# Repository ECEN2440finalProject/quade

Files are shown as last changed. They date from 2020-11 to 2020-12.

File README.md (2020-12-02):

# quade
ECEN 2440 quade code

Repository for RC Quade (Quadruped robot with MSP432 as its base, controlled wirelessly by a remote control with joystick).

ECEN 2440 Final Project Team 11 - Michael L, Terry V, Wyatt S, Ethan C

Fall, 2020

All code files (original and leveraged) can be found here, along with:
  - Texas Instruments MSP432P401R LaunchPad datasheet, header file, and Technical Reference Manual (quade/Datasheet_TechRefMan/)
  - EAGLE PCB schematic and board design files for Arduino Uno shield, for remote control (quade/Arduino_Uno_Shield/)

Works Cited/Leveraged Code:
  - Tyler Davidson: IMU_TestBench code (stIMU.c/.h, pca9685.c/.h, i2c.c/.h, parts of main.c); FirstSteps code (servo.c/.h, parts of gait.c/.h)
  - Paul Stoffregen: RadioHead library (basis of our custom Arduino sketch for RF Link Transmitter)
    - https://github.com/PaulStoffregen/RadioHead
  - Texas Instruments, Inc: MSP432 Driver Library (used for ADC code)
    - adc14.c/.h, cpu.c/.h, debug.h, gpio.c/.h, interrupt.c/.h, sysctl.c/.h, sysctl_a.c/.h
    - https://software-dl.ti.com/msp430/msp430_public_sw/mcu/msp430/MSP432_Driver_Library/latest/index_FDS.html

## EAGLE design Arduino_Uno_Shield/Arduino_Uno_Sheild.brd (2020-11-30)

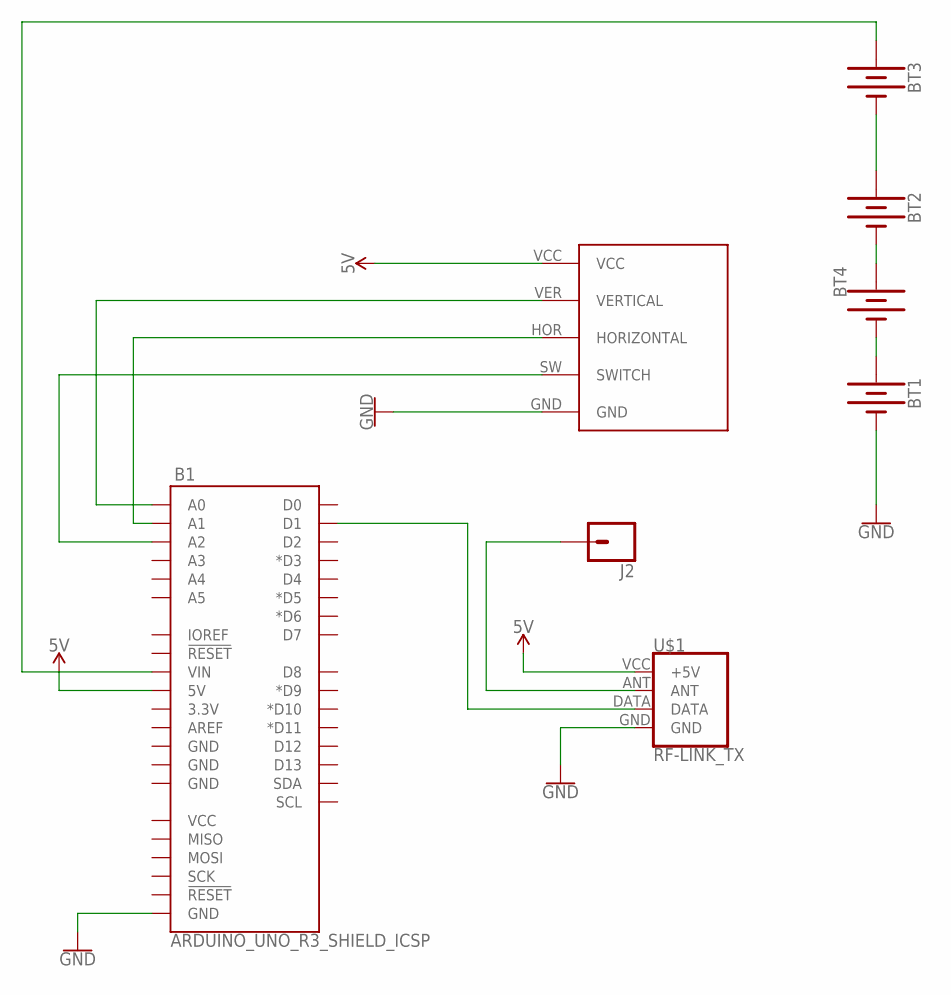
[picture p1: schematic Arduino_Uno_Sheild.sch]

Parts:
B1: ARDUINO_UNO_R3_SHIELD_ICSP; UNO_R3_SHIELD_ICSP
BT1, BT2, BT3, BT4: BATTERY-AAA
J2: CONN_01POGOPIN_HOLE_0.58; 1X01_POGOPIN_HOLE_0.58_DIA
JOYSTICK1: JOYSTICK
U$1: RF-LINK_TX

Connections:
5V: B1.5V, JOYSTICK1.VCC, U$1.VCC (+5V)
GND: B1.GND_ICSP (GND), BT1.GND@1 (-), JOYSTICK1.GND, U$1.GND
unnamed: B1.TX (D1), U$1.DATA
unnamed: J2.1, U$1.ANT
unnamed: B1.A0, JOYSTICK1.VER (VERTICAL)
unnamed: B1.A1, JOYSTICK1.HOR (HORIZONTAL)
unnamed: B1.A2, JOYSTICK1.SW (SWITCH)
unnamed: B1.VIN, BT3.PWR@1 (+)
unnamed: BT2.PWR@1 (+), BT3.GND@1 (-)
unnamed: BT2.GND@1 (-), BT4.PWR@1 (+)
unnamed: BT1.PWR@1 (+), BT4.GND@1 (-)

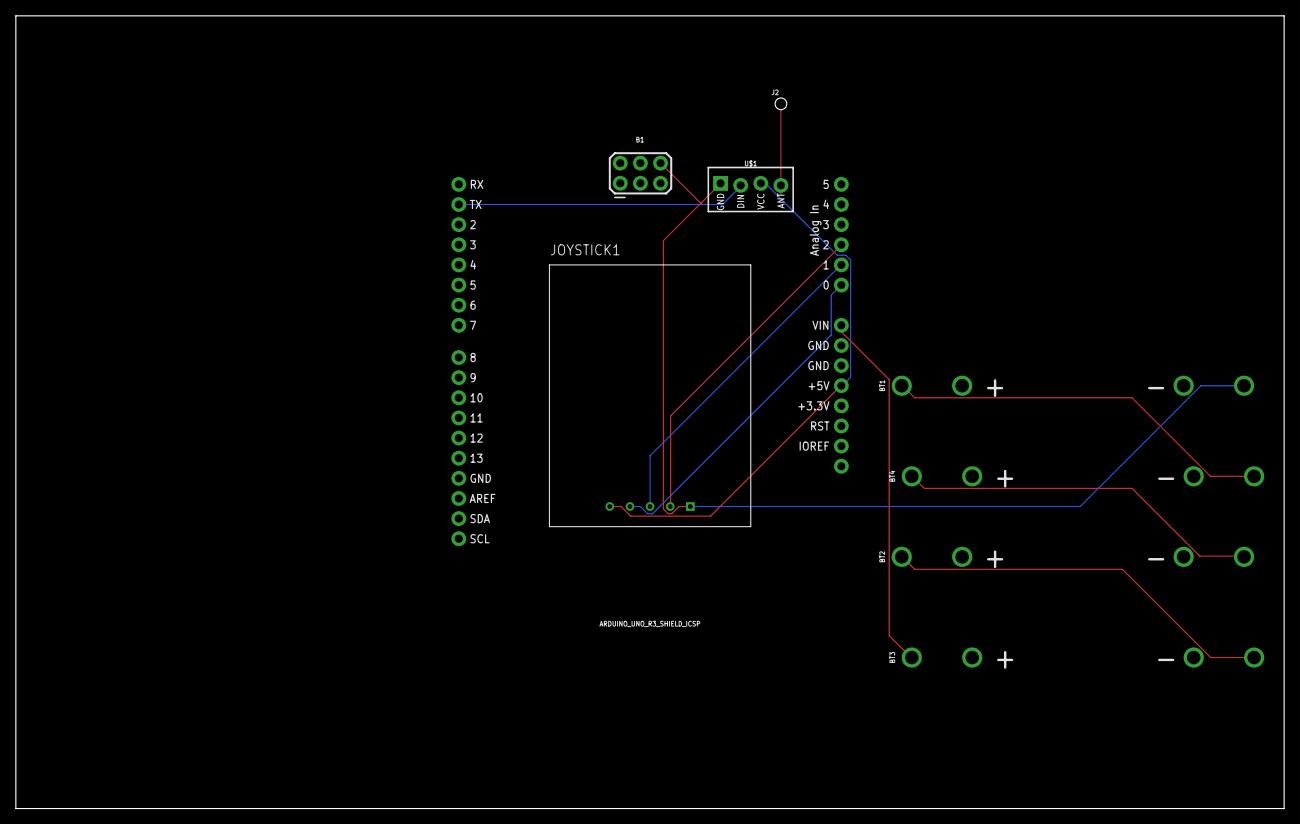
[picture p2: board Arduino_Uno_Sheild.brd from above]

Board: 2 copper layers, 160.0 x 100.0 mm, 8 parts (0 on the bottom side), 11 nets.

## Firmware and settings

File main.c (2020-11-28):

//ATTENTION!!!!
//PLEASE IGNORE BELOW DIAGRAM!!!
//THis diagram was back when I was using my own Naming Convention
//Check servo.h for servo channels



/*This Program is designed to allow all the servos to be attached
 * to the skeleton in a predictable way.
 *
 * In order to have proper orientation and operation of the robot,
 * a consistent convention must be established. Below is a top-down
 * view of the robot. The boxes represent each servo and the name
 * assigned to it. Each Group (A-D) represents a limb, while each
 * number represents a joint (1 is shoulder, 2 is knee)
 *
 *    ____                         ____
 *   /    \                       /    \
 *  /  A2  \      TOP-DOWN       /  B2  \
 *  \______/                     \______/
 *         \ ______       ______ /
 *          |      |     |      |
 *          |  A1  |     |  B1  |
 *          |______|     |______|
 *              |           |
 *  FRONT ------------------------- BACK
 *           ___|__       __|___
 *          |      |     |      |
 *          |  D1  |     |  C1  |
 *          |______|     |______|
 *     ____/                     \____
 *    /    \                     /    \
 *   /  D2  \                   /  C2  \
 *   \______/                   \______/
 *
 * It is very important that all the Shoulder-Knee joints get assembled
 * EXACTLY the same. This will guarantee that all the Knee servos behave
 * the same.
 *
 * When the program is initially started, the servos will move to their
 * center postiton (90 degrees).
 *
 * For the first time using this program
 * MAKE SURE THAT NO SERVOS ARE SECURED TO THE SKELETON!! There is a
 * serious risk that the servos will collide with each other if they
 * aren't secured in the correct position.
 *
 * Once all the servos are centered, it is time to attach the servos
 * the skeleton in what is called the Neutral Position. In the Neutral
 * Position, the horn of the servo should be be in-line or parallel to
 * the body of the servo (or as close as possible). The Horn of the
 * servo is used to secure the servo in the correct position
 *
 * Below is the pinning information to connect servos to PCA9685 board
 *
 *   A1-->Group A, servo 1 to servo pin 0 (of PCA9685)
 *   A2-->Group A, servo 2 to servo pin 1 (of PCA9685)
 *   B1-->Group B, servo 1 to servo pin 2 (of PCA9685)
 *   B2-->Group B, servo 2 to servo pin 3 (of PCA9685)
 *   C1-->Group C, servo 1 to servo pin 4 (of PCA9685)
 *   C2-->Group C, servo 2 to servo pin 5 (of PCA9685)
 *   D1-->Group D, servo 1 to servo pin 6 (of PCA9685)
 *   D2-->Group D, servo 2 to servo pin 7 (of PCA9685)
 *
 * Once all the servos are secured in the Neutral Position,
 * pressing the button (S1) on the MSP432 will cause the robot to stand
 * up.
 *
 * IF THE ROBOT DOES NOT STAND UP CORRECTLY, SOMETHING ELSE IS WRONG!
 * Check:
 *       -Servo Orientation at the knee joints
 *       -Wiring to PCA
 *       -Servo Neutral Position
 *
 * MSP Wiring:
 *
 *         msp432p401r
 *      -----------------
 *     |                 |
 *     |                 |
 *     |             P1.7|-->SCL (PCA9685)
 *     |             P1.6|-->SDA (PCA9685)
 *     |                 |
 *     |                 |
 *     |              3V3|-->VCC (PCA9685)
 *     |              GND|-->GND (PCA9685)
 *     |                 |
 *     |_________________|
 *
 *
 *
 *  By: Tyler Davidson
 *  Date: July 17th, 2020
 *
 *  Modified by: Terry Vis
 *  Date: Nov 9, 2020
 *
 */

#include "msp.h"
#include "i2c.h"
#include "pca9685.h"
#include "servo.h"
#include "stIMU.h"
#include "stdio.h"
#include "assert.h"

#include "uart.h"
#include "RFlink.h"
#include "parse_joystick.h"
#include "gait.h"
#include "thermistor.h"


volatile int state = 0;
/*
 * States:
 * 0 - Quade neutral (don't write data to servos)
 * 1 - Read data from Rx UART buffer, make calculations
 * 2 - Write data to servos
 */

// For joystick:
// Up/left is positive direction
// (outputs high for these directions, low for down/right, 1/2 for neutral)

static RX_UART_BUF_TypeDef rx_uart_buf;
static UART_PAYLOAD_TypeDef uart_payload_struct;
static RX_UART_TypeDef rx_uart_struct, *rx_read_struct;

void main(void)
 {
	WDT_A->CTL = WDT_A_CTL_PW | WDT_A_CTL_HOLD;		// stop watchdog timer
	config_uart();
	config_uart_interrupt();
	config_rx_gpio();
	start_uart();

	// Configure and start ADC
	adc_config();
	adc_pin_config();
	adc_enable_interrupt();
	start_adc();

	// set up Button Interrupt
    P1->DIR &= ~BIT1;
    P1->OUT |= BIT1;
    P1->REN |= BIT1;
    P1->IES |= BIT1;
    P1->IFG = 0;
    P1->IE  |= BIT1;

    // Configure data for Rx buffer
    rx_uart_buf.size = 8;
    rx_uart_buf.read = 0;
    rx_uart_buf.write = 0;

    //enable interrupts
    NVIC_EnableIRQ(PORT1_IRQn);
	__enable_irq();

    I2C_OPEN_STRUCT_TypeDef i2c_open_struct;

    i2c_open_struct.uca10 = 0;                              //no self 10-bit Address
    i2c_open_struct.ucsla10 = 0;                            //no 10-bit Addressing
    i2c_open_struct.ucmm = 0;                               //No Multi-Master
    i2c_open_struct.ucmst = EUSCI_B_CTLW0_MST;              //Master Mode
    i2c_open_struct.ucsselx = EUSCI_B_CTLW0_SSEL__SMCLK;    //SMCLK to be selected (3MHz)
    i2c_open_struct.ucbrx = 30;                             //Prescaler for Selected Clock.
                                                            //(100kHz)

    //This sets up the I2C driver to operate with the
    //correct settings.
    //EUSCI_B0 uses P1.7 as SCL and P1.6 as SDA
    i2c_open(EUSCI_B0, &i2c_open_struct);

    pca9685_init(); //sets up PCA to output at the correct frequency
    config_LIS3MDL();

    int16_t mx, my, mz;
    uint8_t data;
    int i;


    //Neutral Position
    while(state == 0){
        for(i=0; i<200000; i++);
        i2c_start(EUSCI_B0, LIS3MDL_MAG_I2C_ADDRESS, READ, &data, 1, LIS3MDL_MAG_STATUS_REG);
        i2c_start(EUSCI_B0, LIS3MDL_MAG_I2C_ADDRESS, READ, &data, 1, LIS3MDL_MAG_STATUS_REG);
        printf("status 1: %d\n",data);
        for(i=0; i<1000; i++);
        mx = read_magnetometer_x();
        my = read_magnetometer_y();
        mz = read_magnetometer_z();
        printf("x: %d\n", mx);
        printf("y: %d\n", my);
        printf("z: %d\n", mz);
        printf("status: %d\n", data);
        printf("\n");
        printf("\n");
        printf("\n");
        printf("\n");
    }

    int8_t * pos; // pointer to array for position of joystick
    uint8_t err;

    // Infinite loop for Quade motion -- interrupt for other functions
    while (state) {
        if (state==1) {
            err = rx_buf_read(&rx_uart_buf, rx_read_struct);
            joystick_pos(rx_read_struct, pos);
            // check for successful read (make sure buffer is not empty for this cycle)
            // if successful, break out of loop, write to servos next
            state = err ? 1 : 2;
        }

        else if (state==2) {
            // write to servos
            servo_gait(pos);
            state = 1;
        }

        else state = 1; // if state does not equal 1 or 2, set to 1 (read state)
    }

}

// putting this here for ease of struct/buffer handling
void EUSCIA2_IRQHandler(void) {
    // check each flag, then perform necessary function
    if (UART_P->IFG & EUSCI_A_IFG_RXIFG) {
        UART_P->IFG &= ~EUSCI_A_IFG_RXIFG; // clear flag

        // store RXBUF bits, will empty buffer
        uint8_t rx = UART_P->RXBUF & EUSCI_A_RXBUF_RXBUF_MASK;
        *uart_payload_struct.data = rx;

        if (rx_uart_struct.i == rx_uart_struct.length) {
            rx_buf_write(&rx_uart_buf, rx_uart_struct);
            rx_uart_struct.i = 0; // reset iteration variable
        }

        rx_state(rx, &rx_uart_struct);



    }
}

/* Port1 ISR */
void PORT1_IRQHandler(void){
    volatile uint32_t j;

    //Change State to Standing Position
    if(P1->IFG & BIT1)
        state = 1;

    // Delay for switch debounce
    for(j = 0; j < 100000; j++);

    // Initialize standing position
    servo_write(URL,90-45); //Because the Orientations are opposite of the other servos,
    servo_write(LRL,90-45); //the direction the servo must move to stand up is also opposote
    servo_write(URA,90+45);
    servo_write(LRA,90+45);
    servo_write(ULL,90+45);
    servo_write(LLL,90+45);
    servo_write(ULA,90-45); //See Above Comment
    servo_write(LLA,90-45);
    wait_all_reach();

    P1->IFG &= ~BIT1;
}

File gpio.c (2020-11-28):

/* --COPYRIGHT--,BSD
 * Copyright (c) 2017, Texas Instruments Incorporated
 * All rights reserved.
 *
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
 * *  Redistributions of source code must retain the above copyright
 *    notice, this list of conditions and the following disclaimer.
 *
 * *  Redistributions in binary form must reproduce the above copyright
 *    notice, this list of conditions and the following disclaimer in the
 *    documentation and/or other materials provided with the distribution.
 *
 * *  Neither the name of Texas Instruments Incorporated nor the names of
 *    its contributors may be used to endorse or promote products derived
 *    from this software without specific prior written permission.
 *
 * THIS SOFTWARE IS PROVIDED BY THE COPYRIGHT HOLDERS AND CONTRIBUTORS "AS IS"
 * AND ANY EXPRESS OR IMPLIED WARRANTIES, INCLUDING, BUT NOT LIMITED TO,
 * THE IMPLIED WARRANTIES OF MERCHANTABILITY AND FITNESS FOR A PARTICULAR
 * PURPOSE ARE DISCLAIMED. IN NO EVENT SHALL THE COPYRIGHT OWNER OR
 * CONTRIBUTORS BE LIABLE FOR ANY DIRECT, INDIRECT, INCIDENTAL, SPECIAL,
 * EXEMPLARY, OR CONSEQUENTIAL DAMAGES (INCLUDING, BUT NOT LIMITED TO,
 * PROCUREMENT OF SUBSTITUTE GOODS OR SERVICES; LOSS OF USE, DATA, OR PROFITS;
 * OR BUSINESS INTERRUPTION) HOWEVER CAUSED AND ON ANY THEORY OF LIABILITY,
 * WHETHER IN CONTRACT, STRICT LIABILITY, OR TORT (INCLUDING NEGLIGENCE OR
 * OTHERWISE) ARISING IN ANY WAY OUT OF THE USE OF THIS SOFTWARE,
 * EVEN IF ADVISED OF THE POSSIBILITY OF SUCH DAMAGE.
 * --/COPYRIGHT--*/
/* Standard Includes */
#include <stdint.h>

/* DriverLib Includes */
#include <gpio.h>
#include <debug.h>
#include <interrupt.h>


static const uint32_t GPIO_PORT_TO_INT[] =
{ 0x00,
INT_PORT1,
INT_PORT2,
INT_PORT3,
INT_PORT4,
INT_PORT5,
INT_PORT6 };

static const uint32_t GPIO_PORT_TO_BASE[] =
{   0x00,
    (uint32_t)P1,
    (uint32_t)P1+1,
    (uint32_t)P3,
    (uint32_t)P3+1,
    (uint32_t)P5,
    (uint32_t)P5+1,
    (uint32_t)P7,
    (uint32_t)P7+1,
    (uint32_t)P9,
    (uint32_t)P9+1,
    (uint32_t)PJ
};

void GPIO_setAsOutputPin(uint_fast8_t selectedPort, uint_fast16_t selectedPins)
{
    uint32_t baseAddress = GPIO_PORT_TO_BASE[selectedPort];

    HWREG16(baseAddress + OFS_LIB_PASEL0) &= ~selectedPins;
    HWREG16(baseAddress + OFS_LIB_PASEL1) &= ~selectedPins;
    HWREG16(baseAddress + OFS_LIB_PADIR) |= selectedPins;
}


void GPIO_setAsInputPin(uint_fast8_t selectedPort, uint_fast16_t selectedPins)
{
    uint32_t baseAddress = GPIO_PORT_TO_BASE[selectedPort];

    HWREG16(baseAddress + OFS_LIB_PASEL0) &= ~selectedPins;
    HWREG16(baseAddress + OFS_LIB_PASEL1) &= ~selectedPins;
    HWREG16(baseAddress + OFS_LIB_PADIR) &= ~selectedPins;
    HWREG16(baseAddress + OFS_LIB_PAREN) &= ~selectedPins;
}


void GPIO_setAsPeripheralModuleFunctionOutputPin(uint_fast8_t selectedPort,
        uint_fast16_t selectedPins, uint_fast8_t mode)
{

    uint32_t baseAddress = GPIO_PORT_TO_BASE[selectedPort];

    HWREG16(baseAddress + OFS_LIB_PADIR) |= selectedPins;
    switch (mode)
    {
    case GPIO_PRIMARY_MODULE_FUNCTION:
        HWREG16(baseAddress + OFS_LIB_PASEL0) |= selectedPins;
        HWREG16(baseAddress + OFS_LIB_PASEL1) &= ~selectedPins;
        break;
    case GPIO_SECONDARY_MODULE_FUNCTION:
        HWREG16(baseAddress + OFS_LIB_PASEL0) &= ~selectedPins;
        HWREG16(baseAddress + OFS_LIB_PASEL1) |= selectedPins;
        break;
    case GPIO_TERTIARY_MODULE_FUNCTION:
        HWREG16(baseAddress + OFS_LIB_PASEL0) |= selectedPins;
        HWREG16(baseAddress + OFS_LIB_PASEL1) |= selectedPins;
        break;
    }
}


void GPIO_setAsPeripheralModuleFunctionInputPin(uint_fast8_t selectedPort,
        uint_fast16_t selectedPins, uint_fast8_t mode)
{
    uint32_t baseAddress = GPIO_PORT_TO_BASE[selectedPort];

    HWREG16(baseAddress + OFS_LIB_PADIR) &= ~selectedPins;
    switch (mode)
    {
    case GPIO_PRIMARY_MODULE_FUNCTION:
        HWREG16(baseAddress + OFS_LIB_PASEL0) |= selectedPins;
        HWREG16(baseAddress + OFS_LIB_PASEL1) &= ~selectedPins;
        break;
    case GPIO_SECONDARY_MODULE_FUNCTION:
        HWREG16(baseAddress + OFS_LIB_PASEL0) &= ~selectedPins;
        HWREG16(baseAddress + OFS_LIB_PASEL1) |= selectedPins;
        break;
    case GPIO_TERTIARY_MODULE_FUNCTION:
        HWREG16(baseAddress + OFS_LIB_PASEL0) |= selectedPins;
        HWREG16(baseAddress + OFS_LIB_PASEL1) |= selectedPins;
        break;
    }
}


void GPIO_setOutputHighOnPin(uint_fast8_t selectedPort,
        uint_fast16_t selectedPins)
{

    uint32_t baseAddress = GPIO_PORT_TO_BASE[selectedPort];

    HWREG16(baseAddress + OFS_LIB_PAOUT) |= selectedPins;
}


void GPIO_setOutputLowOnPin(uint_fast8_t selectedPort,
        uint_fast16_t selectedPins)
{

    uint32_t baseAddress = GPIO_PORT_TO_BASE[selectedPort];

    HWREG16(baseAddress + OFS_LIB_PAOUT) &= ~selectedPins;
}
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

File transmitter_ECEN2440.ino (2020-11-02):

/*
 * --------------------Constants----------------------
 */

// baud rate
const long baud = 50;

// message length
const uint8_t msgLength = 3;

// start/ stop characters 
const uint16_t Start = 0xF000; //1111_0000_0000_0000
const uint16_t Stop = 0xFF00;  //1111_1111_0000_0000

// post message delay
const long postDelay = 1000;

// analog pins for reading joystick voltage
const int ver = A0;
const int hor = A1;
const int sw = A2;

/*
 * -------------------Structures--------------------
 */

//struct to hold data
struct data{
  uint16_t ver;
  uint16_t hor;
  uint16_t sw;
};

/*
 * -------------------Functions--------------------
 */

//takes in a data struct and fills the struct from the analog sources
//returns nothing
void readPins(data * D){
  D->ver = analogRead(ver);
  D->hor = analogRead(hor);
  D->sw = analogRead(sw);
}

//takes in a two byte variable
//returns void, updates array LSByte first
void parseData(uint16_t twoBytes, uint8_t * arr){
  //parse the 16 bit value into two 8 bit values LSB first
  arr[1] = static_cast<uint8_t>((twoBytes & 0xFF00) >> 8);
  arr[0] = static_cast<uint8_t>(twoBytes & 0x00FF);
}

/*
 * Least Significant Byte first, Least Significant Bit first
 * start   len msg1    msg2    msg3    stop
 * 00__0F__30__LS__MS__LS__MS__LS__MS__00__FF
 */
void sendData(data * D){
  //two byte arrays to send
  uint8_t st[2] = {0,0};
  uint8_t sp[2] = {0,0};
  uint8_t ver[2] = {0,0};
  uint8_t hor[2] = {0,0};
  uint8_t sw[2] = {0,0};

  //two byte ints parsed into bytes and placed in two byte arrays
  parseData(Start, st);
  parseData(Stop, sp);
  parseData(D->ver, ver);
  parseData(D->hor, hor);
  parseData(D->sw, sw);
  
  //send the start 
  Serial.write(st, sizeof(st));
  
  //send the length of the message
  Serial.write(msgLength);
  
  //send the message
  Serial.write(ver, sizeof(ver));
  Serial.write(hor, sizeof(hor));
  Serial.write(sw, sizeof(sw));

  //send the stop
  Serial.write(sp, sizeof(sp));
  
  delay(postDelay);
}
/*
 *--------------------Setup-------------------------
 */
void setup() {
  // open serial port for transmit, uses baud rate from above
  // 8 bit word length, no parity, one stop bit
  Serial.begin(baud, SERIAL_8N1);
}

/*
 *-------------------- Main-------------------------
 */

void loop() {
  // instantiate data struct
  data D = {0,0,0};
  
  //read analog pins
  readPins(&D);
  
  //send the data
  sendData(&D);
}

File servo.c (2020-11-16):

/*
 * servo.c
 *
 * This driver is designed to give xyz control over all the limbs.
 * This will make it much easier to program movement for any kind of gait
 * because the angles can be disregarded. Additional functionality include
 * speed control of the limbs as well as moving several limbs simultaneously
 * thanks to a TimerA interrupt-driven scheduler.
 *
 * Much of this code is inspired by other work.
 * Many of the main functions are built from the work of
 * Belkhir Mohamed. Below is the information that he has requested we provide.
 *
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
 *
 *
 *
 *
 *  Created on: Jul 14, 2020
 *      Author: Tyler Davidson
 *     Updated: Aug 13, 2020
 */
#include "servo.h"
#include "math.h"

void xyz_to_angle(int limb, volatile float *t1, volatile float *t2, volatile float x, volatile float y, volatile float z);
void servo_service(void);
void angle_to_servo(int limb, float t1, float t2);

//flag to indicate the need to service the servos
volatile bool timer_flag = false;

//matrix to organize all servos in the system
const int Servo[4][2] = { {URA,LRA} , {ULA,LLA} , {ULL,LLL} , {URL,LRL} };
//    Servo Matrix
//  __|_0_|_1_|_2_|_3_
//  0_|URA|ULA|URL|ULL
//  1_|LRA|LLA|LRL|LLL


volatile float  pos_now[4][3];         //current coords of each foot (xyz)
volatile float  pos_expected[4][3];    //expected coords of each foot
float           temp_speed[4][3];      //Incremental value to control speed of movement

/*
 * This function is designed to set the starting position for all
 * the limbs and update the arrays for first time use
 */
void servo_startup(){

    int i;
    int j;

    for(i=0; i<4; i++){
        for(j=0; j<2; j++){
            servo_write(Servo[i][j], 90);
        }
    }


    //updates array to represent the correct location
    for(i=0; i<4; i++){
        for(j=0; j<3; j++){
            pos_now[i][j] = 0;
        }
    }


    pos_now[0][0] = A1+A2;
    pos_now[1][0] = -(A1+A2);
    pos_now[2][0] = -(A1+A2);
    pos_now[3][0] = A1+A2;



}


/*
 * Sets up TimerA0 to request servicing of the servos every 20ms.
 * Uses SMCLK @ 3MHz
 */
void servo_timer_init(void){
    TIMER_A0->CCTL[0] &= ~TIMER_A_CCTLN_CCIFG;
    TIMER_A0->CCTL[0] = TIMER_A_CCTLN_CCIE; // TACCR0 interrupt enabled
    TIMER_A0->CCR[0] = 60000;               //count to 60,000 at 3MHz (T = 20ms)
    TIMER_A0->CTL = TIMER_A_CTL_SSEL__SMCLK | // SMCLK , UP mode
            TIMER_A_CTL_MC__UP;
    NVIC_EnableIRQ(TA0_0_IRQn);


}


/*
 * This function checks each limb and moves them by an incrimental amount
 * based on the speed established inside the set_pos function. This function calls two very
 * large functions and requires a lot of time to finish completely. The length of execution
 * is related to the speed established.
 *
 * This function clears t he timer_flag upon completion.
 */
void servo_service(void){
//    P1->OUT |= BIT0;

    static float t1, t2;

    int i;
    int j;
    for(i = 0; i<4; i++){
        for(j = 0; j<3; j++){
            if(abs(pos_now[i][j] - pos_expected[i][j]) >= abs(temp_speed[i][j]))
                pos_now[i][j] += temp_speed[i][j];
            else
                pos_now[i][j] = pos_expected[i][j];
        }
        xyz_to_angle(i, &t1, &t2, pos_now[i][0],pos_now[i][1],pos_now[i][2]);
        angle_to_servo(i,t1,t2);
    }

//    P1->OUT &= ~BIT0;
    timer_flag = false; //lower the flag, servos were updated


}

/*
 * Sets a point for the selected leg to move towards.
 * Use "KEEP" to keep that dimension the same.
 *
 * Breaks up the total distance into several smaller steps along the way.
 * The number of steps is determined by the "speed" variable.
 */
void set_pos(int limb, float x, float y, float z){

    //distance to move in each direction
    float dist_x = 0;
    float dist_y = 0;
    float dist_z = 0;

    if(x != KEEP) dist_x = x - pos_now[limb][0]; //update distance to target in each dimension
    if(y != KEEP) dist_y = y - pos_now[limb][1];
    if(z != KEEP) dist_z = z - pos_now[limb][2];

    //calculate total distance from current point to new point
    float total_distance = sqrt(pow(dist_x,2) + pow(dist_y,2) + pow(dist_z,2));

    //divide distance in a direction by a scaled amount based on speed
    temp_speed[limb][0] = dist_x / total_distance * speed;
    temp_speed[limb][1] = dist_y / total_distance * speed;
    temp_speed[limb][2] = dist_z / total_distance * speed;

    //updated expected position if keeping position
    if(x != KEEP) pos_expected[limb][0] = x;
    if(y != KEEP) pos_expected[limb][1] = y;
    if(z != KEEP) pos_expected[limb][2] = z;

}

/*
 * Wait for Limb to reach the expected position.
 *
 * Also checks the timer_flag each time it loops until the limb
 * are where they should be.
 *
 * Input may ONLY be 0, 1, 2, or 3.
 */
void wait_reach(int limb){

    if(limb<0) assert(false);
    if(limb>3) assert(false);

    while(1){
        if(timer_flag)
            servo_service();
        if(pos_now[limb][0] == pos_expected[limb][0])
            if(pos_now[limb][1] == pos_expected[limb][1])
                if(pos_now[limb][2] == pos_expected[limb][2])
                    return;
    }
}

/*
 * wait for ALL limbs to reach expected position
 */
void wait_all_reach(void){
    int i;
    for(i=0; i<4; i++)
        wait_reach(i);
}



/*
 * Calculates the angle needed for the servos to position the foot at xyz
 *
 * t1 is Yaw of leg
 * t2 is pitch of leg
 *
 * Also handles some of the corrections necessary for desired coordinate system.
 * The Mathematical operations in this function are very intensive.
 *
 */
void xyz_to_angle(int limb, volatile float *t1, volatile float *t2, volatile float x, volatile float y, volatile float z){


    if(limb == LA){
        x = -x;
        y = -y;
    }

    if(limb == LL){
            x = -x;
            y = -y;
        }

    *t1 = (180/3.14) * atan2(y,x);
    *t2 = (180/3.14) * atan2(z,sqrt(pow(x,2) + pow(y,2))-A1);

}

/*
 * Corrects the angles generated by xyz_to_angle to be appropriate for the established coordinate system.
 *
 * This is the function that actually calls servo_write.
 */
void angle_to_servo(int limb, float t1, float t2){

    //transformation to be compatible w/ degree to count equation
    t1 += 90;
    t2 += 90;


    if(limb == RA) t2 = 180 - t2;
    if(limb == LL) t2 = 180 - t2;




    servo_write(Servo[limb][0], t1);
    servo_write(Servo[limb][1], t2);

}


/*
 * IRQ Handler for the TimerA interrupt-driven scheduler.
 */
void TA0_0_IRQHandler(void) {
    // Clear the compare interrupt flag
    TIMER_A0->CCTL[0] &= ~TIMER_A_CCTLN_CCIFG;

    P1->OUT ^= BIT0;
    timer_flag = true;


}

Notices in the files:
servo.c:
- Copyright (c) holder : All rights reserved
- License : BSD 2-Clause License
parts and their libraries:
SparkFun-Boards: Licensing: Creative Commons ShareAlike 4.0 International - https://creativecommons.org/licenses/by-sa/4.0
